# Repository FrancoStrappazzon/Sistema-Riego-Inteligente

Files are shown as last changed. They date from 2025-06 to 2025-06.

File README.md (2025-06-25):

# 💧 Sistema de Riego Inteligente con ESP32
Este proyecto implementa un sistema de riego automático basado en microcontrolador ESP32. Permite controlar una electroválvula en función de las condiciones de temperatura y humedad, e incluye visualización local mediante pantalla OLED y control remoto a través de la app Blynk.

## ⚙️ Características del sistema

  - Microcontrolador: ESP32-WROOM-32
  
  - Sensor: DHT11 (temperatura y humedad)

  - Actuador: Módulo relé 1CH controlando una electroválvula de 12V

  - Visualización local: Pantalla OLED 1.3” (I2C)

  - Visualización y control remoto: App Blynk IoT

  - Fuente: 3.3V (lógica), 12V (electroválvula)

## 🛠️ Herramientas utilizadas

- KiCad 9.0.0 – diseño de esquemático y PCB

- Blynk IoT – plataforma de control y visualización remota

- C++ / Arduino IDE – desarrollo del firmware

- Git + GitHub – control de versiones











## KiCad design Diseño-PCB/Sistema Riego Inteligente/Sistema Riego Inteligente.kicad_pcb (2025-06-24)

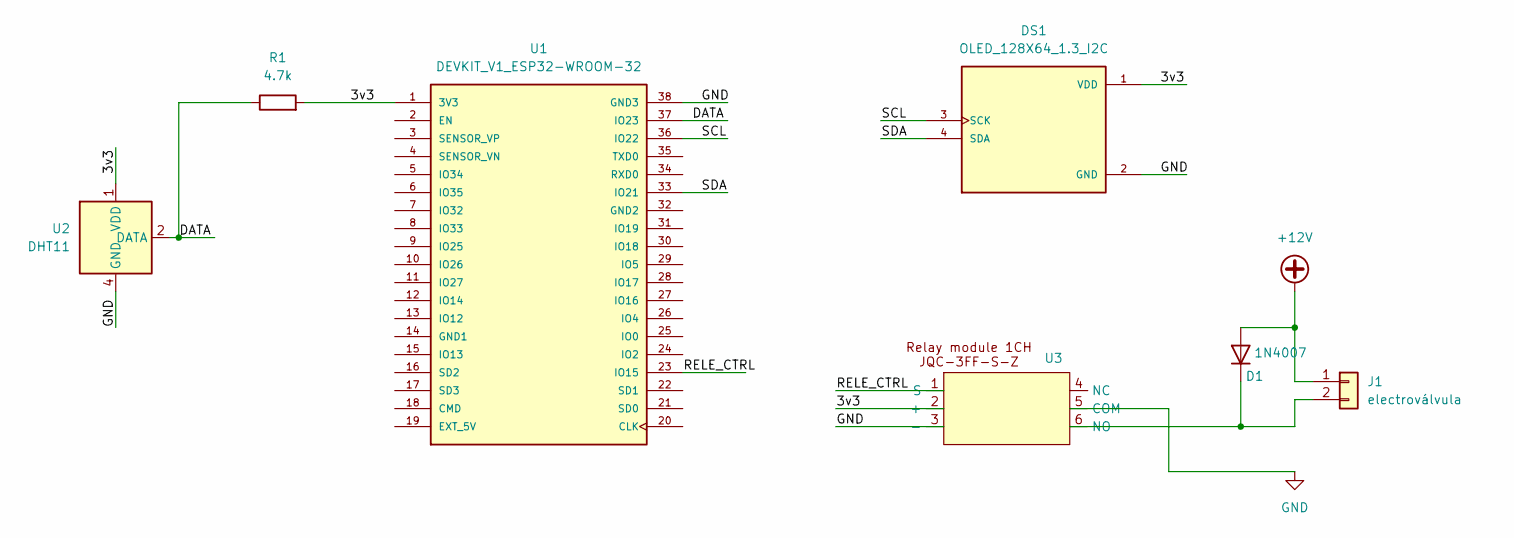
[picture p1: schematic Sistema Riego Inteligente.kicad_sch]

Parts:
D1: 1N4007; D_DO-41_SOD81_P10.16mm_Horizontal
DS1: OLED_128X64_1.3_I2C; LCD_OLED_128X64_1.3_I2C; PARTREV NA
J1: electroválvula; PhoenixContact_GMSTBA_2,5_2-G_1x02_P7.50mm_Horizontal
R1: 4.7k; R_1206_3216Metric
U1: DEVKIT_V1_ESP32-WROOM-32; MODULE_DEVKIT_V1_ESP32-WROOM-32; PARTREV N/A
U2: DHT11; Aosong_DHT11_5.5x12.0_P2.54mm
U3: Relay_Module_1CH

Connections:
+12V: D1.2 (A), J1.1
/3v3: DS1.1 (VDD), R1.2, U1.1 (3V3), U2.1 (VDD), U3.2 (+)
/DATA: R1.1, U1.37 (IO23), U2.2 (DATA)
/RELE_CTRL: U1.23 (IO15), U3.1 (S)
/SCL: DS1.3 (SCK), U1.36 (IO22)
/SDA: DS1.4 (SDA), U1.33 (IO21)
GND: DS1.2 (GND), U1.38 (GND3), U2.4 (GND), U3.3 (-), U3.5 (COM)
unnamed: D1.1 (K), J1.2, U3.6 (NO)

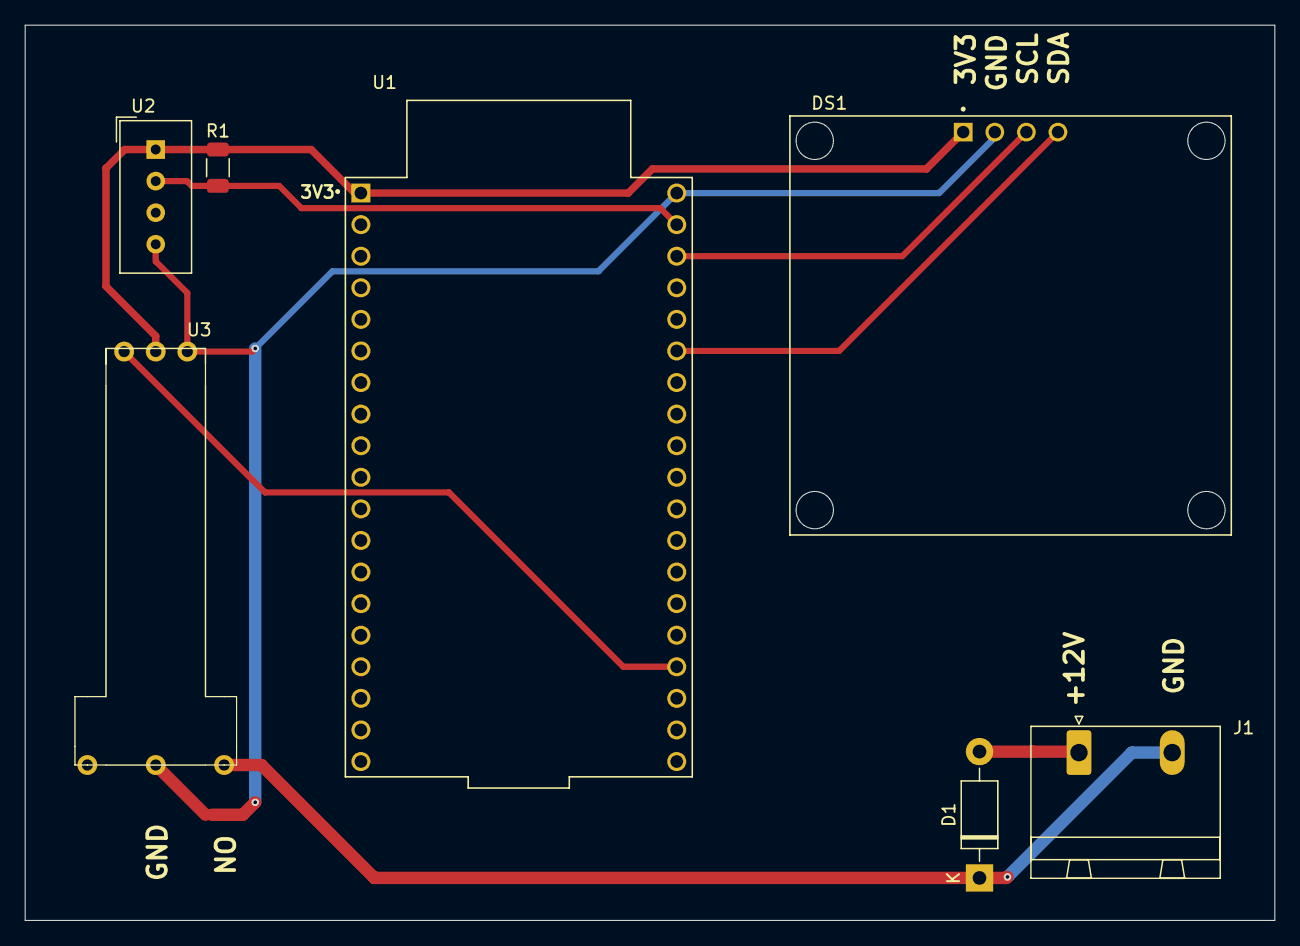
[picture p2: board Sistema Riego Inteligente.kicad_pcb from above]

Board: 2 copper layers, 100.5 x 72.0 mm, 7 parts (0 on the bottom side), 8 nets.

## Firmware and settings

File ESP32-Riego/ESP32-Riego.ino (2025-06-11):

//Variables para conectarse con Blynk
#define BLYNK_TEMPLATE_ID "TMPL27CJAET4n"
#define BLYNK_TEMPLATE_NAME "Sistema de Riego Inteligente"
#define BLYNK_AUTH_TOKEN "YNdTFGrRzLuzupayV_QwZWq09mMPkFAL"

#include "DHT.h" 
#include <Adafruit_GFX.h>
#include <Adafruit_SSD1306.h>
#include <Wire.h>   // I2C
#include <WiFi.h>
#include <WiFiClient.h>
#include <BlynkSimpleEsp32.h>

#define DHTPIN       23
#define DHTTYPE      DHT11
#define SCREEN_WIDTH 128
#define SCREEN_HEIGHT 64


//Red WIFI
char network[] = "Fibertel WiFi804 2.4GHz";
char password[] = "00437475146";

const int evPin     = 15;     // Pin de la electroválvula
float tiempoEv      = 10.0;   // Duración de apertura en segundos

DHT dht(DHTPIN, DHTTYPE);
Adafruit_SSD1306 display(SCREEN_WIDTH, SCREEN_HEIGHT, &Wire, -1);

// Variables para manejar riego con millis()
bool   riegoActivo   = false;
bool   riegoManual  = false;
unsigned long inicioRiego = 0;
unsigned long tiempoUltimoRiego =0;
const unsigned long intervaloRiego = 12UL * 60UL * 60UL * 1000UL; //12 horas en milisegundos


void setup() {
  Serial.begin(9600);
  Blynk.begin(BLYNK_AUTH_TOKEN,network,password);
  dht.begin();
  
  // Pines
  pinMode(evPin, OUTPUT);
  digitalWrite(evPin, LOW);

  // OLED
  if(!display.begin(SSD1306_SWITCHCAPVCC, 0x3C)) {
    Serial.println(F("No se encuentra el OLED!"));
    while(true);
  }
  display.clearDisplay();
  display.setTextColor(SSD1306_WHITE);
  display.setTextSize(2);
  display.setCursor(0,10);
  display.println("Pantalla  OK!");
  display.display();
}

void loop() {
  Blynk.run();
  float h = dht.readHumidity();
  float t = dht.readTemperature();
  // Leo el sensor cada 10 segundos
  static unsigned long lastRead = 0;
  unsigned long ahora = millis(); //para guardar el valor actual de tiempo

  if (millis() - lastRead >= 10000) {
    lastRead = millis();
    leerYMostrarSensor();
    
    // Si humedad < 40% o temp > 30°C, y pasaron 12 horas del ultimo riego, arranca riego
    bool debeRegar = (h < 40.0 || t > 30.0);

    if (!riegoActivo && !riegoManual && debeRegar && ((ahora - tiempoUltimoRiego) >= intervaloRiego)) {
    iniciarRiego();
    tiempoUltimoRiego = ahora;
    }
  }

  // Si el riego está activo, comprobamos el tiempo transcurrido
  if (riegoActivo && !riegoManual && millis() - inicioRiego >= (unsigned long)(tiempoEv * 1000)) {
    finalizarRiego();
  }

}

// Lee DHT y actualiza OLED
void leerYMostrarSensor() {
  float h = dht.readHumidity();
  float t = dht.readTemperature();
  if (isnan(h) || isnan(t)) {
    Serial.println(F("Fallo lectura DHT!"));
    return;
  }
  Serial.printf("Temp: %.1f C, Hum: %.1f %%\n", t, h);

  display.clearDisplay();
  display.setTextSize(2);
  display.setCursor(0, 0);
  display.printf("T:%.1fC\nH:%.1f%%", t, h);
  display.display();

  Blynk.virtualWrite(V0,h);
  Blynk.virtualWrite(V1,t);
}

// Arranca el riego
void iniciarRiego() {
  display.clearDisplay();
  display.setTextSize(2);
  display.setCursor(0, 0);
  display.printf("Iniciando riego...");
  display.display();
  digitalWrite(evPin, HIGH);
  inicioRiego = millis();
  riegoActivo = true;
}

// Finaliza el riego
void finalizarRiego() {
  display.clearDisplay();
  display.setTextSize(2);
  display.setCursor(0, 0);
  display.printf("Riego     finalizado.");
  display.display();
  digitalWrite(evPin, LOW);
  riegoActivo = false;
}

//Control manual del riego desde la app del celular
BLYNK_WRITE(V2){
  int estado = param.asInt();
  if(estado == 1 && !riegoActivo){
    riegoManual = true;
    iniciarRiego();
  }else if (estado == 0 && riegoActivo && riegoManual) {
    finalizarRiego();
    riegoManual = false;
  }
}

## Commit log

2025-06-09 Primer commit, cargo código de ESP32
2025-06-10 Agrego conexion ESP32 con Blynk
2025-06-23 Actualizo footprints y PCB
    [Sistema Riego Inteligente.kicad_pcb, Sistema Riego Inteligente.kicad_sch]
2025-06-23 Actualizo esquemático
    [Sistema Riego Inteligente.kicad_pcb, Sistema Riego Inteligente.kicad_sch]
2025-06-24 Completo ruteo y diseño de PCB
    [Sistema Riego Inteligente.kicad_pcb, Sistema Riego Inteligente.kicad_sch]
